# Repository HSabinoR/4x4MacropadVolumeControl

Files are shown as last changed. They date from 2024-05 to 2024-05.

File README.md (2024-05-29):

# 4x4 Macropad with Volume Control

A macropad with a 4x4 key switch matrix that has 2 layers to it and 5 slide potentiometer used for volume control. I copied the general design of the MisteRdeck stream deck and turned it in to a 4x4 key switch matrix and added space for an extra slide potentiometer. Aswell as changing the design, i used QMK firmware instead of making my own arduino sketch.

## Software Requirements: 
- QMK [Firmware](https://msys.qmk.fm/) and [Toolbox](https://github.com/qmk/qmk_toolbox/releases/tag/beta)
- [Midi-Mixer](https://www.midi-mixer.com/)
- Some type of code editor(any will do)

## Hardware/Machine Requirements
No need to have these things personanlly. As long as you have access to them, it's fine.
- 3D printer
- Soldering iron
- Multimeter

- M3 heat set threaded inserts
- M3x10mm Bolt head screws(I used countersunk head screws as thats all i had on hand)

## Electronic Components:
- 1x Arduino Pro Micro (I went with the one that has a USB C port)
- 16x [key switches](https://www.aliexpress.com/item/1005004388563696.html?spm=a2g0o.order_list.order_list_main.35.30dc1802Wi4ATW)
- 16x [1N4148 Diodes](https://www.aliexpress.com/item/1005006094377496.html?spm=a2g0o.order_list.order_list_main.23.30dc1802Wi4ATW)
- 5x Slide (Linear) Potentiomters (make sure that they are linear and not a logarithmic potentiometer, I got [these](https://www.aliexpress.com/item/1005005032811114.html?spm=a2g0o.order_list.order_list_main.17.30dc1802Wi4ATW))
- A bunch of wires
- USB C/Micro Cable(depending on which Arduino Pro Micro)
- A button to connect between the reset pin and gnd(you can also just use some tweezers)

## Wiring Diagrams


Slide Potentiometers (You will have to be careful with which way round you have the VCC and Gnd on the potentiometer. I ended up having gnd towards the top pins)



Key switch matrix (Make sure that the ```"diode_direction"``` in the [info.json](QMK%20Firmware/info.json) file is set to ```"ROW2COL"``` if you follow my wiring diagram)

MacroPad

Arduino Pro Micro Pinout Diagram

## Things to keep in mind
- You will most likely have to change the pins in this section around:
```json
"matrix_pins": {
    "cols": ["D0", "D4", "C6", "D7"],
    "rows": ["B2", "B5", "B4", "E6"]
},
```
as the pins labelled in the diagrams weren't the exact pins I used.
- You will probably have to cut away at the [base section](STL%20Files/Base.stl) as the Arduino pro micro didn't fit in the hold i designed for it. In fact, you don't need it at all as the hotglue that i used around the USB C port was enough to keep it in place.
- I suggest you use heatshrink tubing, if you have any, to be extra sure that the exposed wires don't touch each other. I didn't use any cause i didn't have any on hand.
- You don't have to spraypaint the case like I did, i just wanted to.
- You can either buy some keycaps or 3D print some. There are plenty of stl files online.
- The [case](STL%20Files/Box.stl) has 3 holes in it as I made an extra bracket to hold a USB hub i had. You can just bring it into any CAD/3D modelling software to patch it.

## QMK Guide
If you've downloaded QMK [Firmware](https://msys.qmk.fm/) correctly, this guide should work.
1.  Open **QMK MSYS**
2.  Run ```qmk setup``` assumming this is the first time you've run **QMK MSYS** (In most situations you will want to answer ```y``` to all of the prompts)
3.  Once ```qmk setup``` is done, run ```cd qmk_firmware/``` to move to the main folder of anything to do with QMK
4.  Run ```qmk new-keyboard -kb keyboardname -u GitHubName -n YourName -l ortho_4x4 -t promicro```. You can replace ```keyboardname```, ```GithubName``` and ```YourName``` with what you want.
5.  Now locate the folder that the previous command created and replace each file in the folder with the ones in the [QMK Firmware](QMK%20Firmware) folder. You can (Make sure to change the pins to the correct ones)
6.  Now you can run ```qmk compile -kb <keyboard> -km <keymap>``` to create a hex file.

7.  Open QMK [toolbox](https://github.com/qmk/qmk_toolbox/releases/tag/beta)
8.  Select the hex file, connect the pro micro to the pc, press the reset button two times and press flash.
   

 If it looks something like this, you've done it correctly.

## Midi-Mixer Guide
1. Create a new profile, go to the controls tab and add 5 faders and 1 button.



2. For each fader and button, press the learn control button while moving the respective slide potentiometer up and down or pressing down on the button.




3. In the groups tab, create 5 groups and assign 1 fader to each



4. Go to the assignments tab and assign each group to an application/device



5. Go to the button tab and assign it to 'Set default outputdevice...' and choose what devices you want to alternate between.



## If you have any issues, let me know

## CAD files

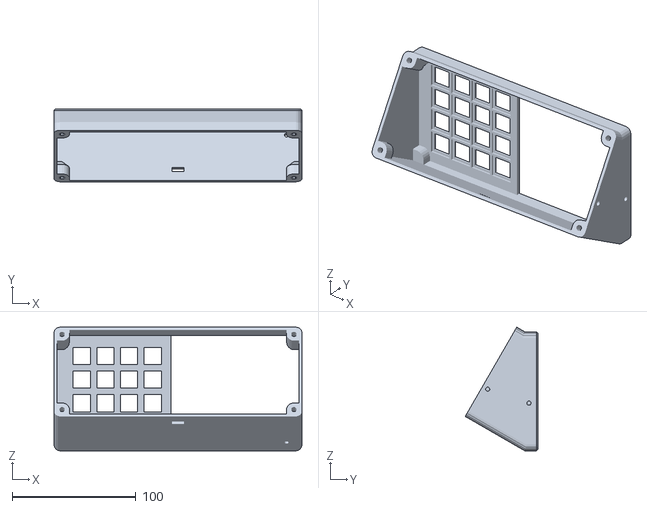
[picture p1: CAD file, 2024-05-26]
STL Files/Box.stl
200.0 x 58.6 x 99.8

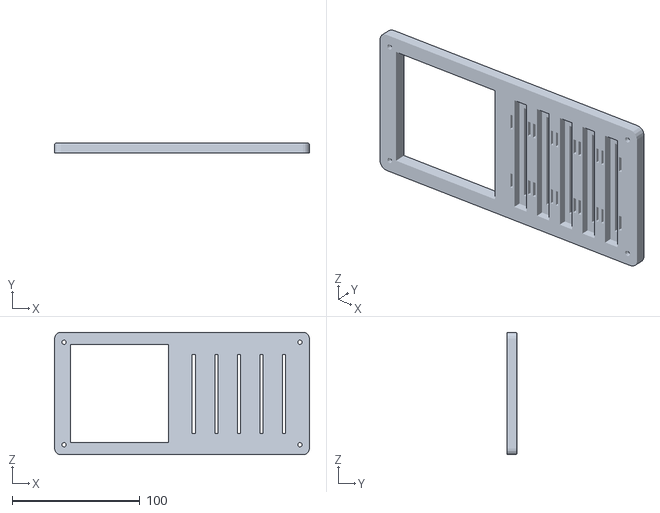
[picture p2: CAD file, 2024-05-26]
STL Files/LID.stl
200.0 x 8.00 x 96.0

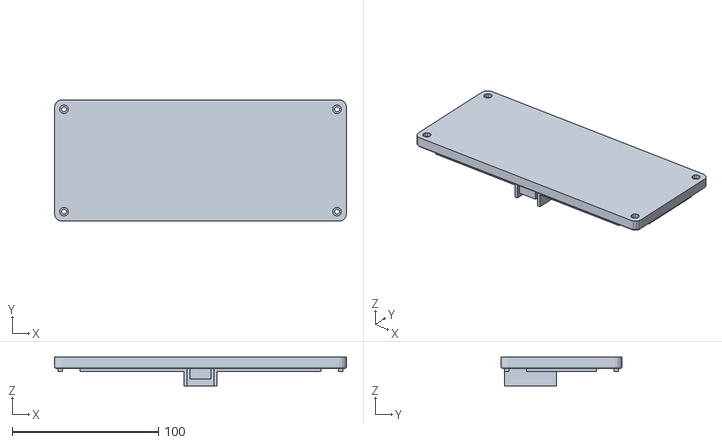
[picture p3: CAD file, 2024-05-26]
STL Files/Base.stl
200.0 x 83.1 x 19.8

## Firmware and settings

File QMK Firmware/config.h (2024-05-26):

// Copyright 2024 Henrique Sabino (@HSabinoR)
// SPDX-License-Identifier: GPL-2.0-or-later

#pragma once

/*
 * Feature disable options
 *  These options are also useful to firmware size reduction.
 */

/* disable debug print */
//#define NO_DEBUG

/* disable print */
//#define NO_PRINT

/* disable action features */
//#define NO_ACTION_LAYER
//#define NO_ACTION_TAPPING
//#define NO_ACTION_ONESHOT

#define MIDI_ADVANCED

#define SLIDER_PINA F5
#define SLIDER_PINB F4
#define SLIDER_PINC F6
#define SLIDER_PIND F7
#define SLIDER_PINE B6

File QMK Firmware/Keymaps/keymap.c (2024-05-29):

// Copyright 2023 QMK
// SPDX-License-Identifier: GPL-2.0-or-later

#include QMK_KEYBOARD_H
#include "analog.h"
#include "qmk_midi.h"

#define MIDI_CC_OFF 0
#define MIDI_CC_ON 127

enum custom_keycodes {
    changeDevice = SAFE_RANGE
};

const uint16_t PROGMEM keymaps[][MATRIX_ROWS][MATRIX_COLS] = {
    
    [0] = LAYOUT_4x4(
        C(S(KC_M)), C(S(KC_D)), changeDevice, LWIN(KC_4),
        KC_MEDIA_PREV_TRACK, KC_MEDIA_PLAY_PAUSE, KC_MEDIA_NEXT_TRACK, KC_MEDIA_STOP,
        LWIN(KC_3), LWIN(KC_5), LWIN(KC_6), KC_AUDIO_MUTE,
        LWIN(KC_L), A(KC_F4), KC_SLEP, TO(1)
    ),
    [1] = LAYOUT_4x4(
        S(KC_F13), S(KC_F14), S(KC_F15), S(KC_F16),
        S(KC_F17), S(KC_F18), S(KC_F19), S(KC_F20),
        S(KC_F21), S(KC_F22), S(KC_F23), S(KC_F24),
        C(S(KC_F13)), C(S(KC_F14)), C(S(KC_F15)), TO(0)
        )
};

bool process_record_user(uint16_t keycode, keyrecord_t *record) {
    switch (keycode) {
        case changeDevice:
            if (record->event.pressed) {
                midi_send_cc(&midi_device, 3, 80, MIDI_CC_ON);
            } else {
                midi_send_cc(&midi_device, 3, 80, MIDI_CC_OFF);
            }
        break;
    }
    return true;
}

uint8_t last_readA = 0;
uint8_t current_readA = 0;
uint8_t last_readB = 0;
uint8_t current_readB = 0;
uint8_t last_readC = 0;
uint8_t current_readC = 0;
uint8_t last_readD = 0;
uint8_t current_readD = 0;
uint8_t last_readE = 0;
uint8_t current_readE = 0;

void slider(void) {
    uint8_t current_layer = get_highest_layer(layer_state);

    uint8_t current_readA = (analogReadPin(SLIDER_PINA) +last_readA)/8; //filter strength
 
    if (current_readA != last_readA ) { // (&midi_device, chan, message, max control value - (current pin reading) >>resolution)
        if (current_layer == 1) {
            midi_send_cc(&midi_device, 2, 0x30, 0x7F - (analogReadPin(SLIDER_PINA) >>3));
        }
        else {
            midi_send_cc(&midi_device, 1, 0x30, 0x7F - (analogReadPin(SLIDER_PINA) >>3));
            }
 
    last_readA = current_readA;
    }
 

    uint8_t current_readB = (analogReadPin(SLIDER_PINB) +last_readB)/8;
 
    if (current_readB != last_readB ) {
        if (current_layer == 1) {
            midi_send_cc(&midi_device, 2, 0x31, 0x7F - (analogReadPin(SLIDER_PINB) >>3));
        }
        else {
            midi_send_cc(&midi_device, 1, 0x31, 0x7F - (analogReadPin(SLIDER_PINB) >>3));
        }
    last_readB = current_readB;
    }


    uint8_t current_readC = (analogReadPin(SLIDER_PINC) +last_readC)/8;
 
    if (current_readC != last_readC ) {
        if (current_layer == 1) {
            midi_send_cc(&midi_device, 2, 0x32, 0x7F - (analogReadPin(SLIDER_PINC) >>3));
        }
        else {
            midi_send_cc(&midi_device, 1, 0x32, 0x7F - (analogReadPin(SLIDER_PINC) >>3));
        }

    last_readC = current_readC;
    }

    uint8_t current_readD = (analogReadPin(SLIDER_PIND) +last_readD)/8;
 
    if (current_readD != last_readD ) {
        if (current_layer == 1) {
            midi_send_cc(&midi_device, 2, 0x33, 0x7F - (analogReadPin(SLIDER_PIND) >>3));
        }
        else {
            midi_send_cc(&midi_device, 1, 0x33, 0x7F - (analogReadPin(SLIDER_PIND) >>3));
        }
 
    last_readD = current_readD;
    }

    uint8_t current_readE = (analogReadPin(SLIDER_PINE) +last_readE)/8;
 
    if (current_readE != last_readE ) {
        if (current_layer == 1) {
            midi_send_cc(&midi_device, 2, 0x34, 0x7F - (analogReadPin(SLIDER_PINE) >>3));
        } else {
            midi_send_cc(&midi_device, 1, 0x34, 0x7F - (analogReadPin(SLIDER_PINE) >>3));
        }
    last_readE = current_readE;
    }
 
}

 
void matrix_scan_user(void) {
    slider();
}
